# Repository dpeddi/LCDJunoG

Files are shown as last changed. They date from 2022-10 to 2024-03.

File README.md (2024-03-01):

Roland Juno G LCD Emulator
==========================

If this is too complex for you you can buy a ready made replacement on https://junoglcd.my-online.store/. Thats not me, but he is affordable, i get a sample from him and it looks good. Since it ship from Uk, you might have to pay customs.

The keyboard Roland Juno G is equipped with an "International Display Works" V0054850 Rev A LCD with PN: 5485SGPABNC

It seems that this part is defective and Roland replaced it with a new revision that was quite expansive
and nowadays isnt available any more.

I looked for a different display unit that would fit the old one.
I've choosen this one: https://www.aliexpress.com/item/1005003033844928.html 

It is jus a little smaller then the old one but it should fit well, but the interface is SPI, while the 
original display was parallel.

Perfect to reduce the number of pins required to connect to a microcontroller.

I connected to the keyboard my hantek 6022BL Logic probe and tried to sniff the data.
The original Hantek software was really poor, so i moved to Sigrok.
After few attempts I had my csv with the sniffed data.
I wrote a small python program to parse the sniffed data and visual look to a result..
Finally i understood the protocol.

I can assume that the original display have two KS0713 controllers that control half display each other.

I connected the keyboard and the display to my ESP32 (I started dreaming to change the color using wifi), 
and after some tests i discovered that the speed of the keyboard bus was too fast to use IRQ, so i tried 
to move to DMA by using the CS1 line as reference clock for the I2C controller.
It worked.. i get half display.. but by reading the ESP32 datasheet I discovered that the second I2C controller
can't be used for a secondary parallel input..

After few reading I decided to buy a Raspberry Pi Pico. The PIO seems really promising...
I connected it... the display connected to SPI is 2 or 3 time faster then ESP... great...
So i implemented a sketch to read data using IRQ... but even the RP2040 failed... 
so i moved to State Machine + DMA... it was a pain... few documentation id didn't worked at all..

I've studied some of the following project located on github to learn something more about dma  
https://github.com/raspberrypi/pico-examples/blob/master/pio/logic_analyser/logic_analyser.c  
https://github.com/gamblor21/rp2040-logic-analyzer/blob/main/rp2040-logic-analyzer.c  
https://github.com/panda5mt/picampinos  
https://github.com/ArduCAM/arducam_mic/blob/master/arducam_mic.c  
https://github.com/pinballpower/code_dmd  
https://github.com/jostlowe/Pico-DMX  

After some attempts i choosed with Pico-DMX, adapted to my needs to get the display working.

BOM:
====

- Raspberry Pi Pico
- Display ILI9488 4.0"
- Some jumper wires
- Some solder and some dil jumper and a solder board and thin cables.

Pinout:
=======

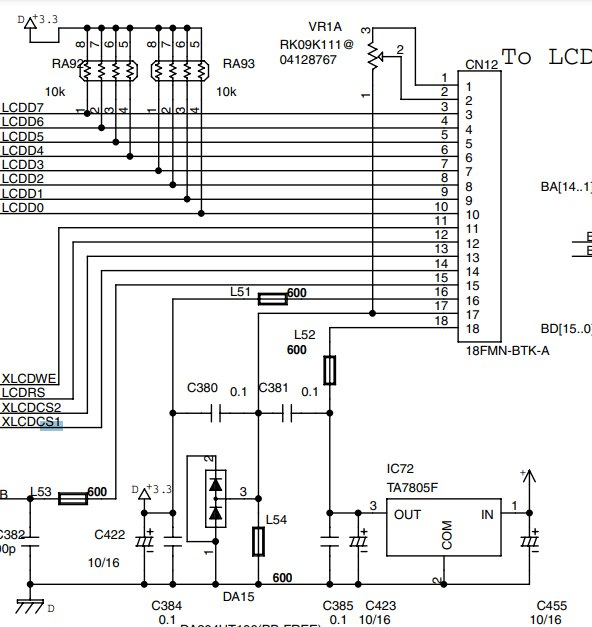
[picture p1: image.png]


Conntecting the RPI pico to the display and the keyboard is quite easy.
You just need to find out the keyboard display pinout by reading the service manual and invent something to connect the rpi to the keyboard.

|JunoG Pin|JunoG Function|RpiPico Pin|
|---|---|---|
|18|+5V|VSYS|
|17|GND|GND|
|16|+3V||
|15|RST|GP14|
|14|CS1|GP12|
|13|CS2|GP13|
|12|RS|GP11|
|11|WE|GP10|
|10|D0|GP2|
|9|D1|GP3|
|8|D2|GP4|
|7|D3|GP5|
|6|D4|GP6|
|5|D5|GP7|
|4|D6|GP8|
|3|D7|GP9|
|2|BRGT|GP26|
|1|BRGT Vref|+3V|

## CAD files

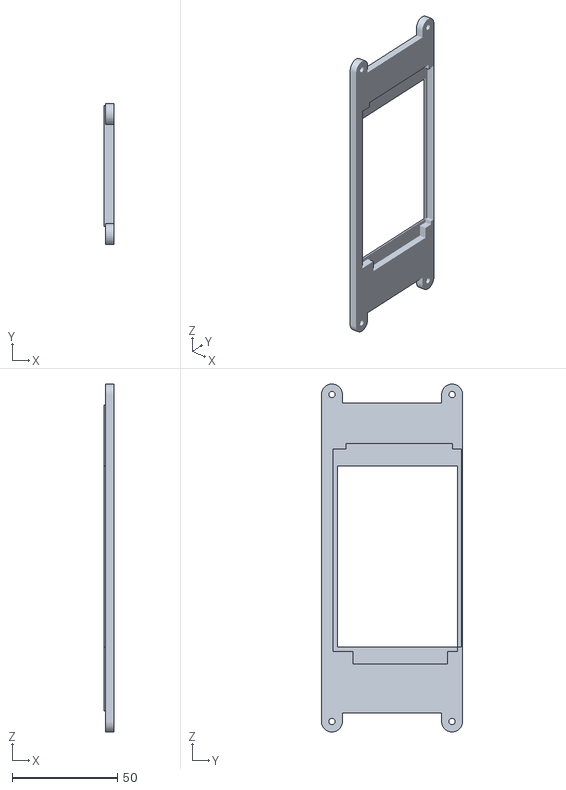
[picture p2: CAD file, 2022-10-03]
junog_display_support v8.stl
4.60 x 67.0 x 165.0

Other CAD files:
junog_display_support v8.f3d

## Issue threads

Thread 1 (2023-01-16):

LCD size

buendias-dev, 2023-01-16:
As described in BOM, is LCD size 5''? I think it's 4'' or 3.5''

Thanks for this outstanding project.

dpeddi, 2023-01-16:
Yes should be a mistake, the display is the 4". Is a bit bigger then the original but it can fit in height

Closed 2023-01-16.

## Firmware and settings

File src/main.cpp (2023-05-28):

/*
 * Copyright (c) 2022 Eddi De Pieri
 * Most code borrowed by Pico-DMX by Jostein Løwer 
 * Modified for performance by bjaan
 *
 * SPDX-License-Identifier: BSD-3-Clause
 * 
 * Description: 
 * Roland Juno G LCD Emulator
 */

// Define in setup to disable all #warnings in library (can be put in User_Setup_Select.h)
#define DISABLE_ALL_LIBRARY_WARNINGS

#include <Arduino.h>

#include <SPI.h>
#include <TFT_eSPI.h> // Hardware-specific library
#ifdef DRAW_SPLASH
#include <LCDJunoG_splash.h>
#endif
#include <LCDJunoG_extra.h>

TFT_eSPI tft = TFT_eSPI();       // Invoke custom library

#include "LCDJunoG.h"
LCDJunoG lcdJunoG_cs1;
LCDJunoG lcdJunoG_cs2;

#define ZOOM_X 2
#define ZOOM_Y 3

uint tft_xoffset = 0;
uint tft_yoffset = 0;

volatile uint16_t buffer_cs1[12*123];
volatile uint16_t buffer_cs2[12*123];
volatile uint8_t back_buffer[240][96/8]; /* max X address register for CS1 and CS2 times max Y register */
volatile uint16_t pixel_x[240]; /* X location (pre-calculated) of actual pixel on new screen */
volatile uint16_t pixel_y[96]; /* Y location (pre-calculated) of actual pixel on new screen */

uint32_t tft_bgcolor = TFT_ORANGE;
uint32_t tft_bgcolor_prev = TFT_BLACK;

void drawPixels(uint8_t val, uint8_t xx, uint8_t yy) {
  int16_t x = pixel_x[yy];
  int8_t y = xx * 8;
  //for (int b = 0; b < 8; b++ ) {
    //if (((val >> b) & 0x1) == 1) tft.drawPixel(x, pixel_y[y+b], TFT_BLACK); else tft.drawPixel(x, pixel_y[y+b], TFT_WHITE);
    //unrolled:
    if ((val & 0x1) == 0x1)   tft.drawPixel(x, pixel_y[y++], TFT_BLACK); else tft.drawPixel(x, pixel_y[y++], tft_bgcolor);
    if ((val & 0x2) == 0x2)   tft.drawPixel(x, pixel_y[y++], TFT_BLACK); else tft.drawPixel(x, pixel_y[y++], tft_bgcolor);
    if ((val & 0x4) == 0x4)   tft.drawPixel(x, pixel_y[y++], TFT_BLACK); else tft.drawPixel(x, pixel_y[y++], tft_bgcolor);
    if ((val & 0x8) == 0x8)   tft.drawPixel(x, pixel_y[y++], TFT_BLACK); else tft.drawPixel(x, pixel_y[y++], tft_bgcolor);
    if ((val & 0x10) == 0x10) tft.drawPixel(x, pixel_y[y++], TFT_BLACK); else tft.drawPixel(x, pixel_y[y++], tft_bgcolor);
    if ((val & 0x20) == 0x20) tft.drawPixel(x, pixel_y[y++], TFT_BLACK); else tft.drawPixel(x, pixel_y[y++], tft_bgcolor);
    if ((val & 0x40) == 0x40) tft.drawPixel(x, pixel_y[y++], TFT_BLACK); else tft.drawPixel(x, pixel_y[y++], tft_bgcolor);
    if ((val & 0x80) == 0x80) tft.drawPixel(x, pixel_y[y  ], TFT_BLACK); else tft.drawPixel(x, pixel_y[y  ], tft_bgcolor);
  //}
}

void fillscreenInterlaced(uint32_t bgcolor) {
  tft.startWrite();
  tft.fillScreen(TFT_BLACK);
  for (uint y = 0; y < 240; y++) {
    for (uint x = 0; x < 12; x++) {
        drawPixels(back_buffer[y][x], x, y);
    }
  }
  tft.endWrite();
}

bool force_refresh = false;

void tft_change_brightness(uint32_t analog_read) {
//42 54  =  50 255  0 -> 12 
  analogWrite( JUNO_BACKLIGHT, ((analog_read - 41) & 0xc) * 17 + 51 );
}

void tft_change_bgcolor(uint32_t analog_read) {
  //Serial.println("ANALOG"+ String(analog_read));
  //min = 42 
  //max = 54
  if (analog_read < 44) {
    tft_bgcolor = TFT_ORANGE;
  } else if ( analog_read >= 44 && analog_read < 46) {
    tft_bgcolor = TFT_SKYBLUE;
  } else if ( analog_read >= 46 && analog_read < 48) {
    tft_bgcolor = TFT_GREENYELLOW;
  } else if ( analog_read >= 48 && analog_read < 50) {
    tft_bgcolor = TFT_YELLOW;
  } else if ( analog_read >= 50 && analog_read < 52) {
    tft_bgcolor = TFT_WHITE;
  } else if ( analog_read >= 52 && analog_read < 54) {
    tft_bgcolor = TFT_CYAN;
  } else if ( analog_read >= 54) {
    tft_bgcolor = TFT_WHITE;
  } 

  if (tft_bgcolor != tft_bgcolor_prev) {
    fillscreenInterlaced(tft_bgcolor);
    tft_bgcolor_prev = tft_bgcolor;
    force_refresh = true;
  }
}

void setup()
{
  analogReadResolution(6);
  uint32_t analog_read = analogRead(JUNO_BRGT);


  //Serial.begin(115200);
  // delay(2000);
  //Serial.setTimeout(50);
  Serial.println("juno g lcd emulator");
  tft.init();
  //tft.setRotation(2);
  tft.setRotation(1);
  tft_xoffset = (tft.width() - 240 * ZOOM_X) / 2 - ((tft.width() - 240 * ZOOM_X) / 2 % ZOOM_X);
  tft_yoffset = (tft.height() - 96 * ZOOM_Y) / 2 - ((tft.height() - 96 * ZOOM_Y) / 2 % ZOOM_Y);

  pinMode( JUNO_BACKLIGHT, OUTPUT );
#ifdef MODE_BRIGHTNESS
  analogWriteResolution(8);
  analogWrite( JUNO_BACKLIGHT, int((analog_read - 2750) / 2.9) );
#else
  digitalWrite(JUNO_BACKLIGHT, HIGH);
#endif

#ifdef DRAW_SPLASH
  tft_change_bgcolor();
  drawBitmapZoom(0, 0, (const uint8_t *)junog, 240, 90, TFT_BLACK);
  delay(500);
#endif

  {  //precalculate new display pixel indices
    for (uint8_t x = 0; x < 240; x++) {
      pixel_x[x] = tft_xoffset + x * ZOOM_X;
    }
    for (uint8_t y = 0; y < 96; y++) {
      pixel_y[y] = tft_yoffset + y * ZOOM_Y;
    }
  }
  { //initialize back buffer
    for (uint8_t x = 0; x < 239; x++) {
      for (uint8_t y = 0; y < 96/8; y++) {
        back_buffer[x][y] = 0;
      }
    }
  }

#define DRAW_INFO
#ifdef DRAW_INFO
#ifdef MODE_BRIGHTNESS
  fillscreenInterlaced(tft_bgcolor);
  tft_change_brightness(analog_read);
#else
  tft_change_bgcolor(analog_read);
#endif
  tft.setTextColor(TFT_BLACK);
  tft.setCursor(0, tft.height()/2 -10  , 2);
  tft.setTextSize(2);
  
  tft.setTextDatum(TC_DATUM);
  tft.drawString("JunoG LCD replacement V2.1.2", tft.width() /2, tft.height() / 2 - 20 );
  //tft.drawString("CPU_FREQ:" + String(rp2040.f_cpu()), tft.width() /2, tft.height() / 2 + 10 );
  delay(500);
  fillscreenInterlaced(tft_bgcolor);
#endif

#ifdef DRAW_PINOUT  
  drawPinout(1000);
#endif
   
  tft.setCursor(0, 0, 2);
  tft.setTextSize(1);
  
  // Setup our DMX Input to read on GPIO 0, from channel 1 to 3
  lcdJunoG_cs1.begin(2, pio0, 1);
  lcdJunoG_cs2.begin(2, pio1, 2);
  lcdJunoG_cs1.read_async(buffer_cs1);
  lcdJunoG_cs2.read_async(buffer_cs2);

  // Setup the onboard LED so that we can blink when we receives packets
  pinMode(LED_BUILTIN, OUTPUT);
}

volatile uint8_t x_cs1 = 0; //X address register for CS1: 4 bit: values 0 up and to including 15: actually max. 12 as 12*8 = 96
volatile uint8_t x_cs2 = 0; //X address register for CS2: 4 bit: values 0 up and to including 15: actually max. 12 as 12*8 = 96
volatile uint8_t y_cs1 = 0; //Y address counter for CS1: 7 bit: values 0 up and to including 127: actually max. 120
volatile uint8_t y_cs2 = 120; //Y address counter for CS2: 7 bit: values 0 up and to including 127: actually max. 120. Here it is set, and later reset to 120, to avoid having to add an offset of 120 all the time

bool led_on = false;
long latest_packet_timestamp_cs1 = 0;
long latest_packet_timestamp_cs2 = 0;

int period = 500;
unsigned long time_now = 0;
unsigned long my_millis = 0;

void loop()
{  
  my_millis = millis();

  if(my_millis >= time_now + period){
    time_now += period;
    uint32_t analog_read = analogRead(JUNO_BRGT);
#ifdef MODE_BRIGHTNESS
        tft_change_brightness(analog_read);
#else        
        tft_change_bgcolor(analog_read);
#endif
#ifdef DEBUG_READ
    tft.fillRect(tft.width() / 2 - 40, 0, 80, 14, TFT_BLACK);
    tft.setTextColor(tft_bgcolor);
    tft.setCursor(tft.width() /2 - 40 , 0, 2);
    tft.setTextSize(1);
  
    tft.setTextDatum(TC_DATUM);
    tft.drawString(String(analog_read), tft.width() /2, 0);
#endif
  }

  if(latest_packet_timestamp_cs1 == lcdJunoG_cs1.latest_packet_timestamp() && latest_packet_timestamp_cs2 == lcdJunoG_cs2.latest_packet_timestamp()) {
    return; // no packet received
  } 
  latest_packet_timestamp_cs1 = lcdJunoG_cs1.latest_packet_timestamp();
  latest_packet_timestamp_cs2 = lcdJunoG_cs2.latest_packet_timestamp();
  tft.startWrite();
  for (uint i = 0; i < 123*12; i++)  
  {
    { //CS 1
      /* 
        buffer_cs1[i] 
          bits: 
          ??????s? vvvvvvvv
          s = R/S (INSTRUCTION/DATA REGISTER SELECTION) pin GP6         
          v = value bits (8 bits: values 0 up to and including 255)
      */
      uint8_t val = buffer_cs1[i] & 0xff /* 00000000 11111111*/;
      uint8_t rs = (buffer_cs1[i] /*000000s0 00000000*/ >> 9) /*00000000 0000000s*/ & 1; 
      if (rs == 0) { //INSTRUCTION REGISTER
#ifdef SHOWCMD
          showcmd( cs, val );
#endif
        if ((val & 0xf0 /*11110000*/) == 0xb0 /*1011000*/) { //Sets the X address at the X address register
          x_cs1 = val & 0x0f /*00001111*/;
          y_cs1 = 0;
        }
      } else if (rs == 1) { //DATA REGISTER
        //writes data on JUNO_D0 to JUNO_D7 pins into display data RAM.
        if (y_cs1 < 120) {  // avoid overflow
          if (back_buffer[y_cs1][x_cs1] != val) {
            back_buffer[y_cs1][x_cs1] = val;
            drawPixels(val, x_cs1, y_cs1);
          }
          y_cs1++; //After the writing instruction, Y address is increased by 1 automatically.
        }
      }    
    }
    { //CS 2
      /* 
        buffer_cs2[i] 
          bits: 
          ??????s? vvvvvvvv
          s = R/S (INSTRUCTION/DATA REGISTER SELECTION) pin GP6         
          v = value bits (8 bits: values 0 up to and including 255)
      */
      uint8_t val = buffer_cs2[i] & 0xff;
      uint8_t rs = (buffer_cs2[i] >> 9) & 1;
      if (rs == 0) { //INSTRUCTION REGISTER
#ifdef SHOWCMD
        showcmd( cs, val );
#endif
        if ((val & 0xf0 /*11110000*/) == 0xb0 /*1011000*/) { //Sets the X address at the X address register
          x_cs2 = val & 0x0f /*00001111*/;
          y_cs2 = 120; // 120 is left most pixel of the right hand part
        }
      } else if (rs == 1) { //DATA REGISTER
        //writes data on JUNO_D0 to JUNO_D7 pins into display data RAM.
        if (y_cs2 >= 120 && y_cs2 < 240) {  // avoid overflow  
          if (back_buffer[y_cs2][x_cs2] != val) {
            back_buffer[y_cs2][x_cs2] = val;
            drawPixels(val, x_cs2, y_cs2);
          }
          y_cs2++; //After the writing instruction, Y address is increased by 1 automatically.
        }
      }
    }
  }
  tft.endWrite();
  // Blink the LED to indicate that a packet was received
  if (!led_on) digitalWrite(LED_BUILTIN, HIGH); else digitalWrite(LED_BUILTIN, LOW);
  led_on != led_on;
}

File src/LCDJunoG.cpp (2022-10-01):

/*
 * Copyright (c) 2021 Jostein Løwer 
 *
 * SPDX-License-Identifier: BSD-3-Clause
 */

#include "LCDJunoG.h"
#include "LCDJunoG.pio.h"

#if defined(ARDUINO_ARCH_MBED)
  #include <clocks.h>
  #include <irq.h>
  #include <Arduino.h> // REMOVE ME
#else
  #include "pico/time.h"
  #include "hardware/clocks.h"
  #include "hardware/irq.h"
#endif

bool prgm_loaded[] = {false,false};
volatile uint prgm_offsets[] = {0,0};
/*
This array tells the interrupt handler which instance has interrupted.
The interrupt handler has only the ints0 register to go on, so this array needs as many spots as there are DMA channels. 
*/
#define NUM_DMA_CHANS 12
volatile LCDJunoG *active_inputs[NUM_DMA_CHANS] = {nullptr};

LCDJunoG::return_code LCDJunoG::begin(uint pin, PIO pio, uint cs)
{
    uint pio_ind = pio_get_index(pio);
    if(!prgm_loaded[pio_ind]) {
        /* 
        Attempt to load the PIO assembly program into the PIO program memory
        */

        if (cs == 1) {
            if (!pio_can_add_program(pio, &LCDJunoG_cs1_program))
            {
                return ERR_INSUFFICIENT_PRGM_MEM;
            }
            prgm_offsets[pio_ind] = pio_add_program(pio, &LCDJunoG_cs1_program);

        } else if (cs == 2) {
            if (!pio_can_add_program(pio, &LCDJunoG_cs2_program))
            {
                return ERR_INSUFFICIENT_PRGM_MEM;
            }
            prgm_offsets[pio_ind] = pio_add_program(pio, &LCDJunoG_cs2_program);
        }
        prgm_loaded[pio_ind] = true;
    }

    /* 
    Attempt to claim an unused State Machine into the PIO program memory
    */

    int sm = pio_claim_unused_sm(pio, false);
    if (sm == -1)
    {
        return ERR_NO_SM_AVAILABLE;
    }

    // Set this pin's GPIO function (connect PIO to the pad)
    pio_sm_set_consecutive_pindirs(pio, sm, pin, 12, false);
    pio_gpio_init(pio, pin);
    {
        uint32_t pin_offset;
        for ( pin_offset = 0; pin_offset < 12; pin_offset++ )
        {
            pio_gpio_init( pio, pin + pin_offset );
        }
    }

    //eddi- gpio_pull_up(pin);

    // Generate the default PIO state machine config provided by pioasm
    pio_sm_config sm_conf;
    if (cs == 1) 
        sm_conf = LCDJunoG_cs1_program_get_default_config(prgm_offsets[pio_ind]);
    else if (cs == 2) 
        sm_conf = LCDJunoG_cs2_program_get_default_config(prgm_offsets[pio_ind]);
    sm_config_set_in_pins(&sm_conf, pin); // for WAIT, IN
    sm_config_set_jmp_pin(&sm_conf, pin); // for JMP

    // Setup the side-set pins for the PIO state machine
    // Shift to right, autopush disabled
    sm_config_set_in_shift(&sm_conf, true, false, 14);
    // Deeper FIFO as we're not doing any TX
    sm_config_set_fifo_join(&sm_conf, PIO_FIFO_JOIN_RX);

    // Load our configuration, jump to the start of the program and run the State Machine
    pio_sm_init(pio, sm, prgm_offsets[pio_ind], &sm_conf);

    _pio = pio;
    _sm = sm;
    _cs = cs;
    _pin = pin;
    _buf = nullptr;
    _cb = nullptr;

    _dma_chan = dma_claim_unused_channel(true);

    if (active_inputs[_dma_chan] != nullptr) {
        return ERR_NO_SM_AVAILABLE;
    }
    active_inputs[_dma_chan] = this;

    return SUCCESS;
}

void LCDJunoG::read(volatile uint16_t *buffer)
{
    if(_buf==nullptr) {
        read_async(buffer);
    }
    unsigned long start = _last_packet_timestamp;
    while(_last_packet_timestamp == start) {
        tight_loop_contents();
    }
}

void lcdjunog_dma_handler() {
    for(int i=0;i<NUM_DMA_CHANS;i++) {
        if(active_inputs[i]!=nullptr && (dma_hw->ints0 & (1u<<i))) {
            dma_hw->ints0 = 1u << i;
            volatile LCDJunoG *instance = active_inputs[i];

            dma_channel_set_write_addr(i, instance->_buf, true);
            pio_sm_exec(instance->_pio, instance->_sm, pio_encode_jmp(prgm_offsets[pio_get_index(instance->_pio)]));
            pio_sm_clear_fifos(instance->_pio, instance->_sm);

#ifdef ARDUINO
            instance->_last_packet_timestamp = millis();
#else
            instance->_last_packet_timestamp = to_ms_since_boot(get_absolute_time());
#endif
            // Trigger the callback if we have one
            if (instance->_cb != nullptr) {
                (*(instance->_cb))((LCDJunoG*)instance);
            }
        }
    }
}

void LCDJunoG::read_async(volatile uint16_t *buffer, void (*inputUpdatedCallback)(LCDJunoG*)) {

    _buf = buffer;
    if (inputUpdatedCallback!=nullptr) {
        _cb = inputUpdatedCallback;
    }

    pio_sm_set_enabled(_pio, _sm, false);

    // Reset the PIO state machine to a consistent state. Clear the buffers and registers
    pio_sm_restart(_pio, _sm);

    //setup dma
    dma_channel_config cfg = dma_channel_get_default_config(_dma_chan);

    // Reading from constant address, writing to incrementing byte addresses
    channel_config_set_transfer_data_size(&cfg, DMA_SIZE_16);
    channel_config_set_read_increment(&cfg, false);
    channel_config_set_write_increment(&cfg, true);

    // Pace transfers based on DREQ_PIO0_RX0 (or whichever pio and sm we are using)
    channel_config_set_dreq(&cfg, pio_get_dreq(_pio, _sm, false));

    //channel_config_set_ring(&cfg, true, 5);
    dma_channel_configure(
        _dma_chan, 
        &cfg,
        NULL,    // dst
        &_pio->rxf[_sm],  // src
        12 * 123,
        false
    );

    dma_channel_set_irq0_enabled(_dma_chan, true);
    irq_set_exclusive_handler(DMA_IRQ_0, lcdjunog_dma_handler);
    irq_set_enabled(DMA_IRQ_0, true);

    //aaand start!
    dma_channel_set_write_addr(_dma_chan, buffer, true);
    pio_sm_exec(_pio, _sm, pio_encode_jmp(prgm_offsets[pio_get_index(_pio)]));
    pio_sm_clear_fifos(_pio, _sm);
#ifdef ARDUINO
    _last_packet_timestamp = millis();
#else
    _last_packet_timestamp = to_ms_since_boot(get_absolute_time());
#endif

    pio_sm_set_enabled(_pio, _sm, true);
}

unsigned long LCDJunoG::latest_packet_timestamp() {
    return _last_packet_timestamp;
}

uint LCDJunoG::pin() {
    return _pin;
}

void LCDJunoG::end()
{
    // Stop the PIO state machine
    pio_sm_set_enabled(_pio, _sm, false);

    // Remove the PIO program from the PIO program memory
    uint pio_id = pio_get_index(_pio);
    bool inuse = false;
    for(uint i=0;i<NUM_DMA_CHANS;i++) {
        if(i==_dma_chan) {
            continue;
        }
        if(pio_id == pio_get_index(active_inputs[i]->_pio)) {
            inuse = true;
            break;
        }
    }
    if(!inuse) {
        prgm_loaded[pio_id] = false;
        if (_cs == 1)
            pio_remove_program(_pio, &LCDJunoG_cs1_program, prgm_offsets[pio_id]);
        else if (_cs == 2)
            pio_remove_program(_pio, &LCDJunoG_cs2_program, prgm_offsets[pio_id]);

        prgm_offsets[pio_id]=0;
    }

    // Unclaim the sm
    pio_sm_unclaim(_pio, _sm);

    dma_channel_unclaim(_dma_chan);
    active_inputs[_dma_chan] = nullptr;

    _buf = nullptr;
}

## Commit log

2022-09-27 da segni di vita
2022-10-03 analogread need a first sample to get right value
2022-10-03 added 3d print project
    [junog_display_support v8.f3d, junog_display_support v8.stl]
2022-11-03 add schematic
2023-05-28 apply most bjaan changes plus brightness and color tuning thanks https://github.com/bjaan/roland-juno-g-display-replacement for performance improvements
    [main.cpp]
